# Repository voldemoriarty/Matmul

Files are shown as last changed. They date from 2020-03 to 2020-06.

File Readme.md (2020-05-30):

# Matmul: Hardware Matrix Multiplier Generator
The goal of this project is to create a configurable Integer Matrix Multiplier 
using SpinalHDL. The multiplier has 2 streaming input ports and 1 streaming 
output port. The elements are streamed in order a11, a12 ... a1n, a21 ... ann.
The results are streamed out in the same order. This makes it possible to 
chain multiplication by connecting outputs to inputs of other Multipliers.

## Architecture 
The architecture of a PE (Processing Engine) is a simple 2D array of MAC units with FIFOs for synchronization.
The input elements get fed into their respective FIFO (only the elements that are needed in
the calculation are pushed into the FIFO, this is accomplished via Counters tracking the 
coordinates of the element) as they arrive and are fed into the MAC when both `a` and `b` 
inputs are ready. The FIFOs are `N` deep where `N` is the dimension of the MAC Array. Thanks
to the FIFOs, streams `A` and `B` need not be synchronized.

The MAC itself is a 3 stage pipeline

Since all the computations happen in parallel, the PE only needs 3 more cycles after `a` 
and `b` matrices have been streamed into it to finish the computation. After that it will 
begin streaming the results, clear the MACs and begin accepting new inputs.

Assuming Data is sent every clock cycle, `N^2 + 3` cycles are needed for
the computation and `N` more cycles to transfer the results

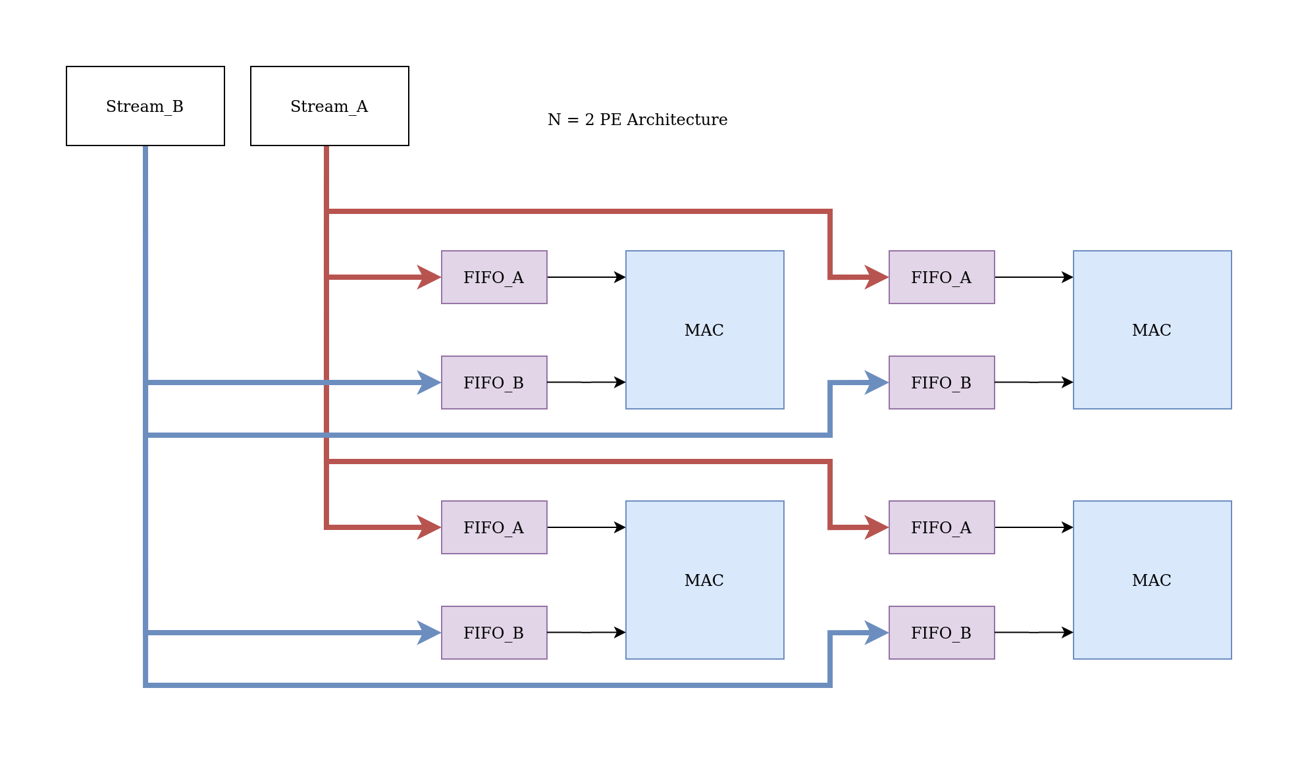
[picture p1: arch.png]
Arch


## Variants
 - Streaming Outputs (`PeStream`): The outputs are streamed one value at a time
 - MemoryMapped Outputs (`PeMM`, NOT TESTED): The outputs are available 3 cycles after 
 inputs
 have been streamed accessed with a simple MM interface

## Interfaces
 - Stream: `valid/ready/payload` interface directly pin compatible with
 Avalon-ST interface (DMA ready)
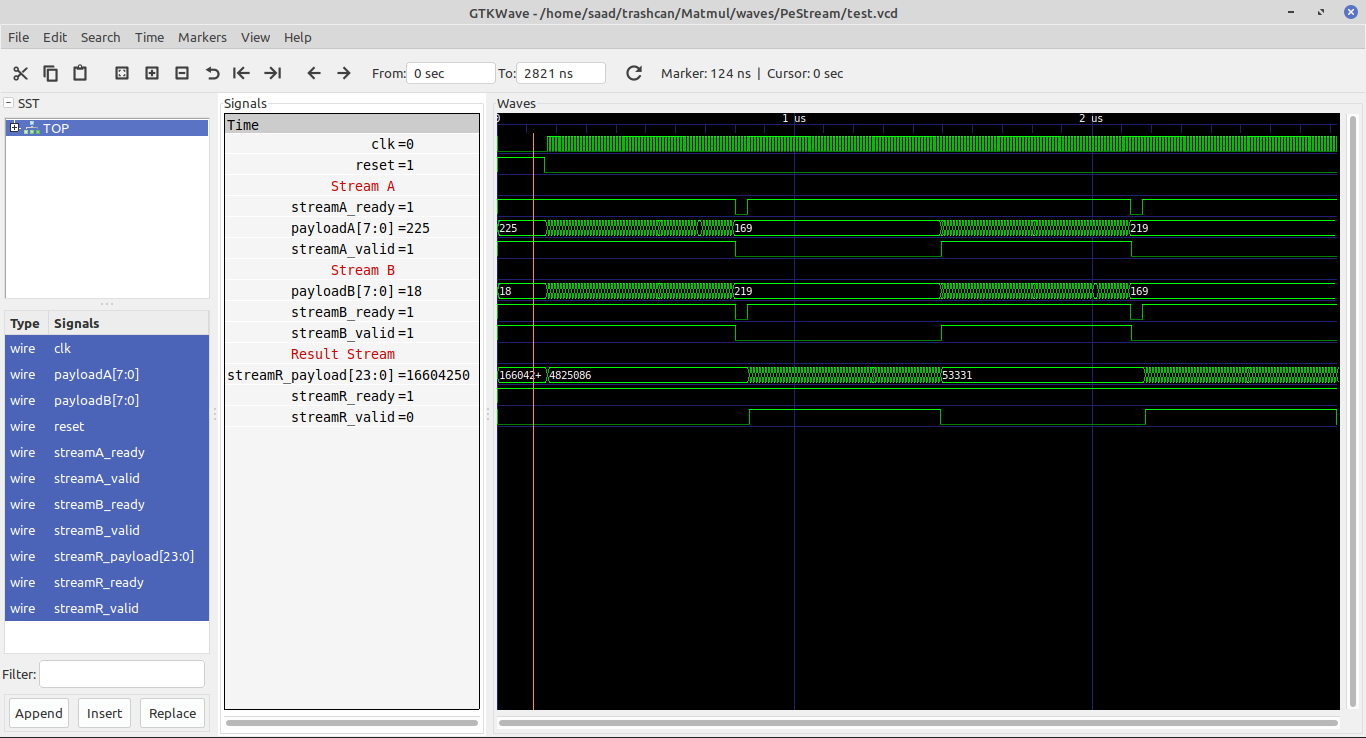
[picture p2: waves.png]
Verilator Waves
 
 - MM: (NOT READY)

## FPGA Area/Frequency (`PeStream`)

| FPGA | PeConfig | Area | Fmax |
| --- | --- | --- | ---|
| Cyclone II | N = 5, 16 bit input, 32 bit output | 9,389 LEs, 50 9-bit Mults | 172.95 MHz |
| Cyclone II | N = 5, 8 bit input, 16 bit output | 5,033 LEs, 25 9-bit Mults| 196.43 MHz |

Numbers obtained from Quartus 13.0 with Optimization = Speed

## Demo Project
In the `de10nano` directory is a Demo project that 
couples a N=5, 16-bit in, 32-bit out PE with Altera's 
modular SGDMAs and a NIOS-II/e on a DE10 Nano board
(Cyclone V SoC) at 130 MHz. In the directory is the Quartus project,
Qsys system and NIOS-II Eclipse project. Uses a `Makefile`
to build the HW `.sof` and program it

The C code uses the DMAs to transfer data to/from the 
PE and then prints the output on JTAG-UART console 

```C
#define DIM   5
#define SIZE  (DIM*DIM)

volatile uint16_t A [SIZE] = {
    0,  1,  2,  3,  4,
    5,  6,  7,  8,  9,
    10, 11, 12, 13, 14,
    15, 16, 17, 18, 19,
    20, 21, 22, 23, 24
};

volatile uint16_t B [SIZE] = {
    0,  1,  2,  3,  4,
    5,  6,  7,  8,  9,
    10, 11, 12, 13, 14,
    15, 16, 17, 18, 19,
    20, 21, 22, 23, 24
};
```
Product:

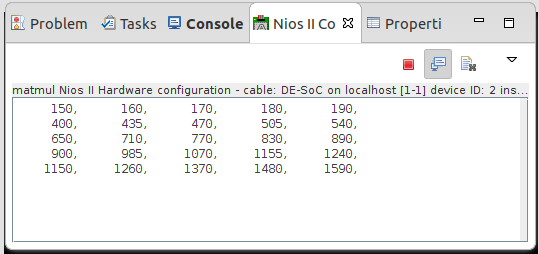
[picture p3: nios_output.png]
Results


## Directory Layout
 - `src/*`: SpinalHDL sources and tests
 - `de10nano/*`: Quartus demo project
 - `de10nano/software`: NIOS-II application
 - `PeStream.v`: Verilog source file needed for Qsys generate
 - `de10nano/Matmul_hw.tcl`: Qsys component for PE
 - `jar/*`: Contains the generator jar
 
## Dependencies
 - `SpinalHDL`
 - `scalatest`
 - `scallop`

## Running the generator
 - Use IDEA OR
 - Run the jar file `jar/Matmul.jar`

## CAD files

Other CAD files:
de10nano/stp1.stp

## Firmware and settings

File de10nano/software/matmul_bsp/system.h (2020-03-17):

/*
 * system.h - SOPC Builder system and BSP software package information
 *
 * Machine generated for CPU 'nios2' in SOPC Builder design 'soc_system'
 * SOPC Builder design path: ../../soc_system.sopcinfo
 *
 * Generated: Tue Mar 17 17:53:22 PKT 2020
 */

/*
 * DO NOT MODIFY THIS FILE
 *
 * Changing this file will have subtle consequences
 * which will almost certainly lead to a nonfunctioning
 * system. If you do modify this file, be aware that your
 * changes will be overwritten and lost when this file
 * is generated again.
 *
 * DO NOT MODIFY THIS FILE
 */

/*
 * License Agreement
 *
 * Copyright (c) 2008
 * Altera Corporation, San Jose, California, USA.
 * All rights reserved.
 *
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
 * This agreement shall be governed in all respects by the laws of the State
 * of California and by the laws of the United States of America.
 */

#ifndef __SYSTEM_H_
#define __SYSTEM_H_

/* Include definitions from linker script generator */
#include "linker.h"


/*
 * CPU configuration
 *
 */

#define ALT_CPU_ARCHITECTURE "altera_nios2_gen2"
#define ALT_CPU_BIG_ENDIAN 0
#define ALT_CPU_BREAK_ADDR 0x00020820
#define ALT_CPU_CPU_ARCH_NIOS2_R1
#define ALT_CPU_CPU_FREQ 130000000u
#define ALT_CPU_CPU_ID_SIZE 1
#define ALT_CPU_CPU_ID_VALUE 0x00000000
#define ALT_CPU_CPU_IMPLEMENTATION "tiny"
#define ALT_CPU_DATA_ADDR_WIDTH 0x12
#define ALT_CPU_DCACHE_LINE_SIZE 0
#define ALT_CPU_DCACHE_LINE_SIZE_LOG2 0
#define ALT_CPU_DCACHE_SIZE 0
#define ALT_CPU_EXCEPTION_ADDR 0x00000020
#define ALT_CPU_FLASH_ACCELERATOR_LINES 0
#define ALT_CPU_FLASH_ACCELERATOR_LINE_SIZE 0
#define ALT_CPU_FLUSHDA_SUPPORTED
#define ALT_CPU_FREQ 130000000
#define ALT_CPU_HARDWARE_DIVIDE_PRESENT 0
#define ALT_CPU_HARDWARE_MULTIPLY_PRESENT 0
#define ALT_CPU_HARDWARE_MULX_PRESENT 0
#define ALT_CPU_HAS_DEBUG_CORE 1
#define ALT_CPU_HAS_DEBUG_STUB
#define ALT_CPU_HAS_ILLEGAL_INSTRUCTION_EXCEPTION
#define ALT_CPU_HAS_JMPI_INSTRUCTION
#define ALT_CPU_ICACHE_LINE_SIZE 0
#define ALT_CPU_ICACHE_LINE_SIZE_LOG2 0
#define ALT_CPU_ICACHE_SIZE 0
#define ALT_CPU_INST_ADDR_WIDTH 0x12
#define ALT_CPU_NAME "nios2"
#define ALT_CPU_OCI_VERSION 1
#define ALT_CPU_RESET_ADDR 0x00000000


/*
 * CPU configuration (with legacy prefix - don't use these anymore)
 *
 */

#define NIOS2_BIG_ENDIAN 0
#define NIOS2_BREAK_ADDR 0x00020820
#define NIOS2_CPU_ARCH_NIOS2_R1
#define NIOS2_CPU_FREQ 130000000u
#define NIOS2_CPU_ID_SIZE 1
#define NIOS2_CPU_ID_VALUE 0x00000000
#define NIOS2_CPU_IMPLEMENTATION "tiny"
#define NIOS2_DATA_ADDR_WIDTH 0x12
#define NIOS2_DCACHE_LINE_SIZE 0
#define NIOS2_DCACHE_LINE_SIZE_LOG2 0
#define NIOS2_DCACHE_SIZE 0
#define NIOS2_EXCEPTION_ADDR 0x00000020
#define NIOS2_FLASH_ACCELERATOR_LINES 0
#define NIOS2_FLASH_ACCELERATOR_LINE_SIZE 0
#define NIOS2_FLUSHDA_SUPPORTED
#define NIOS2_HARDWARE_DIVIDE_PRESENT 0
#define NIOS2_HARDWARE_MULTIPLY_PRESENT 0
#define NIOS2_HARDWARE_MULX_PRESENT 0
#define NIOS2_HAS_DEBUG_CORE 1
#define NIOS2_HAS_DEBUG_STUB
#define NIOS2_HAS_ILLEGAL_INSTRUCTION_EXCEPTION
#define NIOS2_HAS_JMPI_INSTRUCTION
#define NIOS2_ICACHE_LINE_SIZE 0
#define NIOS2_ICACHE_LINE_SIZE_LOG2 0
#define NIOS2_ICACHE_SIZE 0
#define NIOS2_INST_ADDR_WIDTH 0x12
#define NIOS2_OCI_VERSION 1
#define NIOS2_RESET_ADDR 0x00000000


/*
 * Define for each module class mastered by the CPU
 *
 */

#define __ALTERA_AVALON_JTAG_UART
#define __ALTERA_AVALON_ONCHIP_MEMORY2
#define __ALTERA_AVALON_SYSID_QSYS
#define __ALTERA_MSGDMA
#define __ALTERA_NIOS2_GEN2


/*
 * RAM configuration
 *
 */

#define ALT_MODULE_CLASS_RAM altera_avalon_onchip_memory2
#define RAM_ALLOW_IN_SYSTEM_MEMORY_CONTENT_EDITOR 0
#define RAM_ALLOW_MRAM_SIM_CONTENTS_ONLY_FILE 0
#define RAM_BASE 0x0
#define RAM_CONTENTS_INFO ""
#define RAM_DUAL_PORT 0
#define RAM_GUI_RAM_BLOCK_TYPE "AUTO"
#define RAM_INIT_CONTENTS_FILE "soc_system_RAM"
#define RAM_INIT_MEM_CONTENT 1
#define RAM_INSTANCE_ID "NONE"
#define RAM_IRQ -1
#define RAM_IRQ_INTERRUPT_CONTROLLER_ID -1
#define RAM_NAME "/dev/RAM"
#define RAM_NON_DEFAULT_INIT_FILE_ENABLED 0
#define RAM_RAM_BLOCK_TYPE "AUTO"
#define RAM_READ_DURING_WRITE_MODE "DONT_CARE"
#define RAM_SINGLE_CLOCK_OP 0
#define RAM_SIZE_MULTIPLE 1
#define RAM_SIZE_VALUE 131072
#define RAM_SPAN 131072
#define RAM_TYPE "altera_avalon_onchip_memory2"
#define RAM_WRITABLE 1


/*
 * System configuration
 *
 */

#define ALT_DEVICE_FAMILY "Cyclone V"
#define ALT_ENHANCED_INTERRUPT_API_PRESENT
#define ALT_IRQ_BASE NULL
#define ALT_LOG_PORT "/dev/null"
#define ALT_LOG_PORT_BASE 0x0
#define ALT_LOG_PORT_DEV null
#define ALT_LOG_PORT_TYPE ""
#define ALT_NUM_EXTERNAL_INTERRUPT_CONTROLLERS 0
#define ALT_NUM_INTERNAL_INTERRUPT_CONTROLLERS 1
#define ALT_NUM_INTERRUPT_CONTROLLERS 1
#define ALT_STDERR "/dev/jtagUART"
#define ALT_STDERR_BASE 0x21098
#define ALT_STDERR_DEV jtagUART
#define ALT_STDERR_IS_JTAG_UART
#define ALT_STDERR_PRESENT
#define ALT_STDERR_TYPE "altera_avalon_jtag_uart"
#define ALT_STDIN "/dev/jtagUART"
#define ALT_STDIN_BASE 0x21098
#define ALT_STDIN_DEV jtagUART
#define ALT_STDIN_IS_JTAG_UART
#define ALT_STDIN_PRESENT
#define ALT_STDIN_TYPE "altera_avalon_jtag_uart"
#define ALT_STDOUT "/dev/jtagUART"
#define ALT_STDOUT_BASE 0x21098
#define ALT_STDOUT_DEV jtagUART
#define ALT_STDOUT_IS_JTAG_UART
#define ALT_STDOUT_PRESENT
#define ALT_STDOUT_TYPE "altera_avalon_jtag_uart"
#define ALT_SYSTEM_NAME "soc_system"


/*
 * feederA_DMA_csr configuration
 *
 */

#define ALT_MODULE_CLASS_feederA_DMA_csr altera_msgdma
#define FEEDERA_DMA_CSR_BASE 0x21040
#define FEEDERA_DMA_CSR_BURST_ENABLE 1
#define FEEDERA_DMA_CSR_BURST_WRAPPING_SUPPORT 0
#define FEEDERA_DMA_CSR_CHANNEL_ENABLE 0
#define FEEDERA_DMA_CSR_CHANNEL_ENABLE_DERIVED 0
#define FEEDERA_DMA_CSR_CHANNEL_WIDTH 8
#define FEEDERA_DMA_CSR_DATA_FIFO_DEPTH 32
#define FEEDERA_DMA_CSR_DATA_WIDTH 16
#define FEEDERA_DMA_CSR_DESCRIPTOR_FIFO_DEPTH 8
#define FEEDERA_DMA_CSR_DMA_MODE 1
#define FEEDERA_DMA_CSR_ENHANCED_FEATURES 0
#define FEEDERA_DMA_CSR_ERROR_ENABLE 0
#define FEEDERA_DMA_CSR_ERROR_ENABLE_DERIVED 0
#define FEEDERA_DMA_CSR_ERROR_WIDTH 8
#define FEEDERA_DMA_CSR_IRQ 31
#define FEEDERA_DMA_CSR_IRQ_INTERRUPT_CONTROLLER_ID 0
#define FEEDERA_DMA_CSR_MAX_BURST_COUNT 8
#define FEEDERA_DMA_CSR_MAX_BYTE 1024
#define FEEDERA_DMA_CSR_MAX_STRIDE 1
#define FEEDERA_DMA_CSR_NAME "/dev/feederA_DMA_csr"
#define FEEDERA_DMA_CSR_PACKET_ENABLE 0
#define FEEDERA_DMA_CSR_PACKET_ENABLE_DERIVED 0
#define FEEDERA_DMA_CSR_PREFETCHER_ENABLE 0
#define FEEDERA_DMA_CSR_PROGRAMMABLE_BURST_ENABLE 0
#define FEEDERA_DMA_CSR_RESPONSE_PORT 2
#define FEEDERA_DMA_CSR_SPAN 32
#define FEEDERA_DMA_CSR_STRIDE_ENABLE 0
#define FEEDERA_DMA_CSR_STRIDE_ENABLE_DERIVED 0
#define FEEDERA_DMA_CSR_TRANSFER_TYPE "Full Word Accesses Only"
#define FEEDERA_DMA_CSR_TYPE "altera_msgdma"


/*
 * feederA_DMA_descriptor_slave configuration
 *
 */
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

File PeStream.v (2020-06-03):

// Generator : SpinalHDL v1.4.0    git head : ecb5a80b713566f417ea3ea061f9969e73770a7f
// Date      : 03/06/2020, 15:52:01
// Component : PeStream



module Fifo (
  input      [15:0]   io_push_data,
  input               io_push_en,
  output     [15:0]   io_pop_data,
  input               io_pop_en,
  output reg          io_pop_valid,
  output              io_full,
  output              io_empty,
  input               clk,
  input               reset 
);
  reg        [15:0]   _zz_2_;
  wire                _zz_3_;
  wire                _zz_4_;
  wire       [1:0]    _zz_5_;
  wire       [0:0]    _zz_6_;
  wire       [2:0]    _zz_7_;
  wire       [2:0]    _zz_8_;
  wire       [0:0]    _zz_9_;
  wire       [2:0]    _zz_10_;
  wire       [2:0]    _zz_11_;
  reg        [2:0]    wPtr;
  reg        [2:0]    rPtr;
  reg        [3:0]    count;
  reg        [15:0]   mem_0;
  reg        [15:0]   mem_1;
  reg        [15:0]   mem_2;
  reg        [15:0]   mem_3;
  reg        [15:0]   mem_4;
  wire       [7:0]    _zz_1_;
  wire                countLogic_push;
  wire                countLogic_pop;

  assign _zz_3_ = (io_pop_en && (! io_empty));
  assign _zz_4_ = (io_push_en && (! io_full));
  assign _zz_5_ = {countLogic_push,countLogic_pop};
  assign _zz_6_ = (1'b0);
  assign _zz_7_ = {2'd0, _zz_6_};
  assign _zz_8_ = (wPtr + (3'b001));
  assign _zz_9_ = (1'b0);
  assign _zz_10_ = {2'd0, _zz_9_};
  assign _zz_11_ = (rPtr + (3'b001));
  always @(*) begin
    case(rPtr)
      3'b000 : begin
        _zz_2_ = mem_0;
      end
      3'b001 : begin
        _zz_2_ = mem_1;
      end
      3'b010 : begin
        _zz_2_ = mem_2;
      end
      3'b011 : begin
        _zz_2_ = mem_3;
      end
      default : begin
        _zz_2_ = mem_4;
      end
    endcase
  end

  assign io_empty = (count == (4'b0000));
  assign io_full = (count == (4'b0101));
  assign _zz_1_ = ({7'd0,(1'b1)} <<< wPtr);
  assign io_pop_data = _zz_2_;
  always @ (*) begin
    if(_zz_3_)begin
      io_pop_valid = 1'b1;
    end else begin
      io_pop_valid = 1'b0;
    end
  end

  assign countLogic_push = (io_push_en && (! io_full));
  assign countLogic_pop = (io_pop_en && (! io_empty));
  always @ (posedge clk or posedge reset) begin
    if (reset) begin
      wPtr <= (3'b000);
      rPtr <= (3'b000);
      count <= (4'b0000);
    end else begin
      if(_zz_4_)begin
        wPtr <= ((wPtr == (3'b100)) ? _zz_7_ : _zz_8_);
      end
      if(_zz_3_)begin
        rPtr <= ((rPtr == (3'b100)) ? _zz_10_ : _zz_11_);
      end
      case(_zz_5_)
        2'b01 : begin
          count <= (count - (4'b0001));
        end
        2'b10 : begin
          count <= (count + (4'b0001));
        end
        default : begin
          count <= count;
        end
      endcase
    end
  end

  always @ (posedge clk) begin
    if(_zz_4_)begin
      if(_zz_1_[0])begin
        mem_0 <= io_push_data;
      end
      if(_zz_1_[1])begin
        mem_1 <= io_push_data;
      end
      if(_zz_1_[2])begin
        mem_2 <= io_push_data;
      end
      if(_zz_1_[3])begin
        mem_3 <= io_push_data;
      end
      if(_zz_1_[4])begin
        mem_4 <= io_push_data;
      end
    end
  end


endmodule
//Fifo_1_ replaced by Fifo
//Fifo_2_ replaced by Fifo
//Fifo_3_ replaced by Fifo
//Fifo_4_ replaced by Fifo
//Fifo_5_ replaced by Fifo
//Fifo_6_ replaced by Fifo
//Fifo_7_ replaced by Fifo
//Fifo_8_ replaced by Fifo
//Fifo_9_ replaced by Fifo
//Fifo_10_ replaced by Fifo
//Fifo_11_ replaced by Fifo
//Fifo_12_ replaced by Fifo
//Fifo_13_ replaced by Fifo
//Fifo_14_ replaced by Fifo
//Fifo_15_ replaced by Fifo
//Fifo_16_ replaced by Fifo
//Fifo_17_ replaced by Fifo
//Fifo_18_ replaced by Fifo
//Fifo_19_ replaced by Fifo
//Fifo_20_ replaced by Fifo
//Fifo_21_ replaced by Fifo
//Fifo_22_ replaced by Fifo
//Fifo_23_ replaced by Fifo
//Fifo_24_ replaced by Fifo
//Fifo_25_ replaced by Fifo
//Fifo_26_ replaced by Fifo
//Fifo_27_ replaced by Fifo
//Fifo_28_ replaced by Fifo
//Fifo_29_ replaced by Fifo
//Fifo_30_ replaced by Fifo
//Fifo_31_ replaced by Fifo
//Fifo_32_ replaced by Fifo
//Fifo_33_ replaced by Fifo
//Fifo_34_ replaced by Fifo
//Fifo_35_ replaced by Fifo
//Fifo_36_ replaced by Fifo
//Fifo_37_ replaced by Fifo
//Fifo_38_ replaced by Fifo
//Fifo_39_ replaced by Fifo
//Fifo_40_ replaced by Fifo
//Fifo_41_ replaced by Fifo
//Fifo_42_ replaced by Fifo
//Fifo_43_ replaced by Fifo
//Fifo_44_ replaced by Fifo
//Fifo_45_ replaced by Fifo
//Fifo_46_ replaced by Fifo
//Fifo_47_ replaced by Fifo
//Fifo_48_ replaced by Fifo
//Fifo_49_ replaced by Fifo
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

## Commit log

2020-05-30 Change Fifo to implement is Registers instead of Memory blocks. Fixes the hold time issue. Also remove the MLAB attribute
    [PeStream.v]
2020-05-30 Remove mlab attribute switches from the generator
